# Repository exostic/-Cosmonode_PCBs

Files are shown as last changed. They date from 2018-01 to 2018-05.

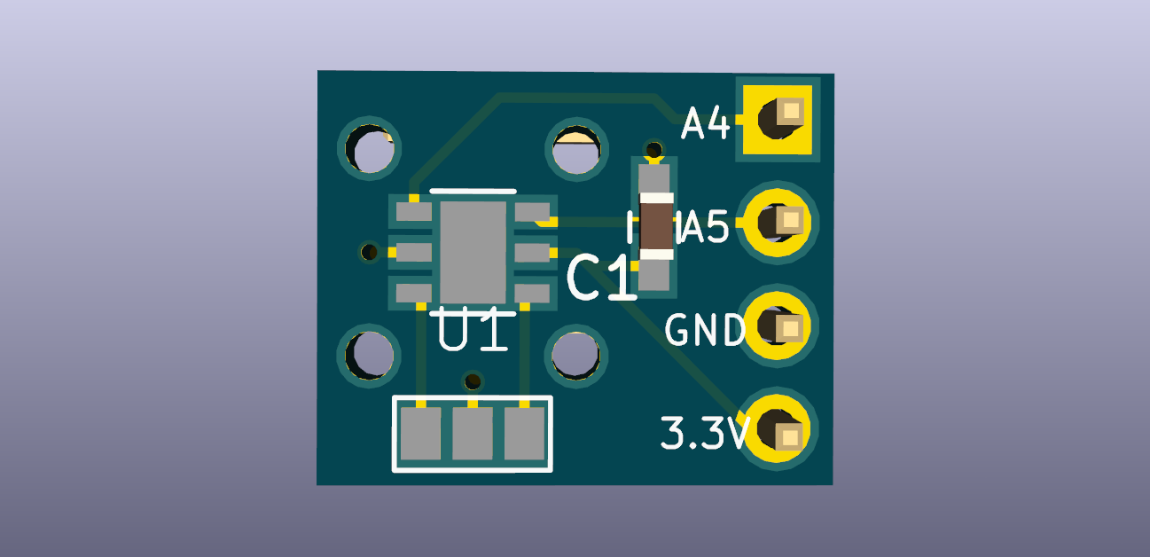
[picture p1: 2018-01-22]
Cosmonode_ext01/docs/Cosmonode_ext01.png

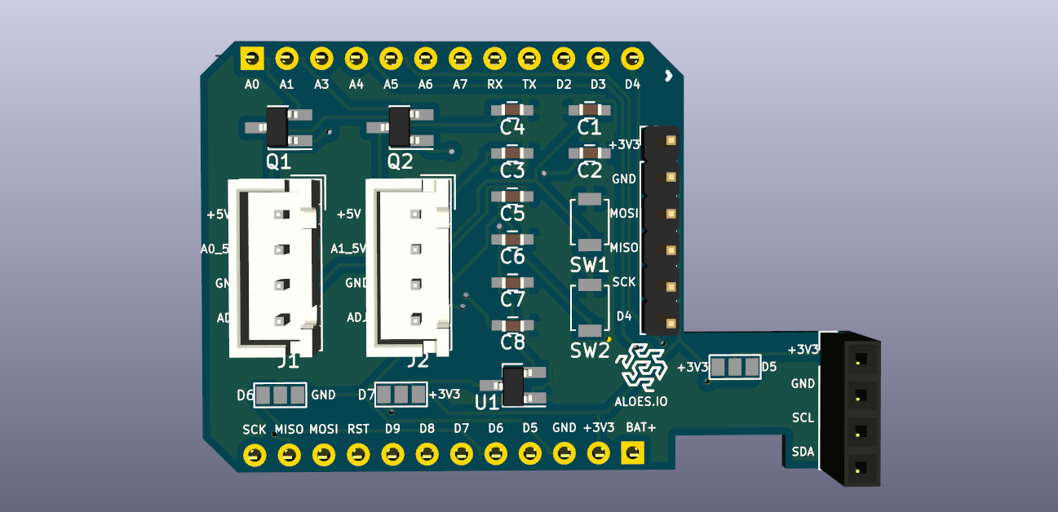
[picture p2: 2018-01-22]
Cosmonode_ext02/docs/Cosmonode_ext02.png

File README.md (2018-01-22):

# Cosmonode v0.7

Universal node, plug and play extensions to ease sensors connection.

## Features

	- Compile and flash with Arduino IDE
	- MCU = ATMega328P-AU
	- radio = RN2483 / RFM69CW ( communications based on LoRaWan or MySensors protocol )
	- 3.3V regulation ( XC6206P332MR )
	- Powered by 3.7V LiPo battery ( 2 pins JST connector )
	- Battery charging ( MCP7831 )
	- State LED's
	- Jumpers to activate radio reset, LED's, on/off switch
	- Button for reset / config mode, or anything else!
	- ATSHA204 to allow hardware unique signature ( no use with RN2483 )

## Projects

Each directory contains Kicad plans, 3D plans, gerber, descriptive .png and .pdf files.

	- ext01 : BME280, Temperature + Humidity + Pression sensor ( only here for the footprint )
	- ext02 : XKC-Y25, Liquid level sensor
	- ext03 : Various connectors ( I2C, Digital, Analog )
	- ext04 : PT100 3 wire, Temperature sensor
	- ext05 : ISP header + micro USB to TTL 
	- ext06 : Analog pH Sensor - BNC probe (WIP)
	- ext07 : MHZ19, CO2 sensor

## Board pinout

	A0 = /
	A1 = /
	A2 = ATSHA204 Input
	A3 = Battery voltage report
	A4 = SDA
	A5 = SCL
	A6 = * LED, jumper J9 ( used as RN2483 Tx )
	A7 = * LED, jumper J14 ( used as RN2483 Rx )
	D0 = RX
	D1 = TX
	D2 = * WakeInterrupt from RN2483, jumper J6 - RFM69 DI0
	D3 = ButtonInterrupt, jumper JP2 ( used to chose mode )
	D4 = /
	D5 = /
	D6 = /
	D7 = /
	D8 = /
	D9 = * RN2483 Reset, jumper J3 - RFM69 Reset
	D10 = RN2483 Rx - RFM69 NSS
	D11 = RN2483 Tx - RFM69 MOSI
	D12 = RFM69 MISO
	D13 = RFM69 SCK
	*optionnal, solder jumper

## Roadmap

--> changelog.md

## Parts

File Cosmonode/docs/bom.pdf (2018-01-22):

Cosmonode

Reference Value | Footprint
U1 | ATMEGA328P-AU | Housings_QFP:TQFP-32_7x7mm_Pitch0.8mm
C2 | 100nF | Capacitors_SMD:C_0603_HandSoldering
C1 | 100nF | Capacitors_SMD:C_0603_HandSoldering
C7 | 100nF | Capacitors_SMD:C_0603_HandSoldering
C3 | 100nF | Capacitors_SMD:C_0603_HandSoldering
R3 | 10k | Resistors_SMD:R_0603_HandSoldering
R8 | 1M | Resistors_SMD:R_0603_HandSoldering
R9 | 470k | Resistors_SMD:R_0603_HandSoldering
C5 | 47uF | Capacitors_Tantalum_SMD:CP_Tantalum_Case-A_EIA-3216-18_Reflow
C6 | 4.7uF | Capacitors_SMD:C_0603_HandSoldering
C8 | 100nF | Capacitors_SMD:C_0603_HandSoldering
R7 | 100k | Resistors_SMD:R_0603_HandSoldering
U5 | XC6206P332MR | TO_SOT_Packages_SMD:TSOT-23
U6 | ATSHA204 | TO_SOT_Packages_SMD:TSOT-23
R4 | 1k | Resistors_SMD:R_0603_HandSoldering
R5 | 1k | Resistors_SMD:R_0603_HandSoldering
C4 | 47uF | Capacitors_Tantalum_SMD:CP_Tantalum_Case-A_EIA-3216-18_Reflow
R6 | | 0 Resistors_SMD:R_0603_HandSoldering
SW1 | SW_DIP_x01 | Buttons_Switches_THT:SW_Tactile_SPST_Angled_PTS645Vx58-2LFS
Y1 | Crystal_GND2 | SMD-RESONATOR-8MHZ-33PF:X3-SMD-3.6X1.3X0.8MM
J1 | CONN_01X12 | Pin_Headers:Pin_Header_Straight_1x12_Pitch2.54mm
J2 | CONN_01X12 | Pin_Headers:Pin_Header_Straight_1x12_Pitch2.54mm
J4 | OSHW | Symbols:OSHW-Logo_7.5x8mm_Copper
U2 | RFM69CW | w_rf_modules:RFM12B_SMD
J5 | CONN_01X02 | Connectors_JST:JST_PH_B2B-PH-K_02x2.00mm_Straight
J10 | WEEE_Logo | Symbols:WEEE-Logo_4.2x6mm_SilkScreen
J11 | Aloes_Logo | Aloes:Aloes
J12 | Aloes_mini_Logo | Aloes:Aloes_mini
U3 | RN2483 | RN2483:RN2483
U7 | MCP73811T-420I/OT TO_SOT_Packages_SMD:SOT-23-5_HandSoldering
J3 | GS2 | Connectors:GS2
D1 | MBR0520 | Diodes_SMD:D_SOD-123
D3 | LED | LEDs:LED_0603_HandSoldering
R12 | 1k | Resistors_SMD:R_0603_HandSoldering
D2 | MBR0520 | Diodes_SMD:D_SOD-123
R11 | R | Resistors_SMD:R_0603_HandSoldering
J13 | CONN_01X05 | Pin_Headers:Pin_Header_Straight_1x05_Pitch2.54mm
C9 | 100nF | Capacitors_SMD:C_0603_HandSoldering
J8 | USB_OTG | Connectors_USB:USB_Micro-B_Molex-105017-0001
R14 | 1k | Resistors_SMD:R_0603_HandSoldering
R13 | 1k | Resistors_SMD:R_0603_HandSoldering
D4 | LED | LEDs:LED_0603_HandSoldering
D5 | LED | LEDs:LED_0603_HandSoldering
J9 | GS2 | Connectors:GS2
J14 | GS2 | Connectors:GS2
P1 | COAX | sma:EDGE_SMA_5
J6 | GS2 | Connectors:GS2
JP1 | Jumper_NO_Small | Pin_Headers:Pin_Header_Straight_1x02_Pitch2.54mm
JP2 | Jumper_NC_Dual | Pin_Headers:Pin_Header_Straight_1x03_Pitch2.54mm

Datasheet | Description
Good | SMD PMIC%3B LDO%3B Vin 6V%3B 3.0V%3B 200mA%3B Without En%3B 1-Ch
Unavailable | Crypto Authentication%2C Sot-23-3

DOCUMENTATION

MF | Package | Price | MP | Farnell
Torex | SOT-23-3 Torex | 0.58 USD XC6206P302MR
Microchip SOT-23-3 Microchip None | ATSHA204-TSU-T

1608592

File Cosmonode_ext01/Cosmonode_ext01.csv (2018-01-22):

Reference | Value | Footprint | Datasheet | Price | Package | MF | Availability | Description
J1 | CONN_01X04 | Pin_Headers:Pin_Header_Angled_1x04_Pitch2.54mm
U1 | SI7020-A20-YM0R | SI7020-A20-YM0R:SON100P300X300X80-7N | SI7020-A20-YM0R | 3.20 USD | DFN-6 Silicon Labs | Silicon Labs | Unavailable | Digital Temperature/Humidity Sensor 6-Pin DFN T/R
J3 | GS3 | Connectors:GS3
C1 | 100nF | Capacitors_SMD:C_0603_HandSoldering
J2 | CONN_01X01 | Wire_Pads:SolderWirePad_single_1-2mmDrill
J4 | CONN_01X01 | Wire_Pads:SolderWirePad_single_1-2mmDrill
J5 | CONN_01X01 | Wire_Pads:SolderWirePad_single_1-2mmDrill
J6 | CONN_01X01 | Wire_Pads:SolderWirePad_single_1-2mmDrill

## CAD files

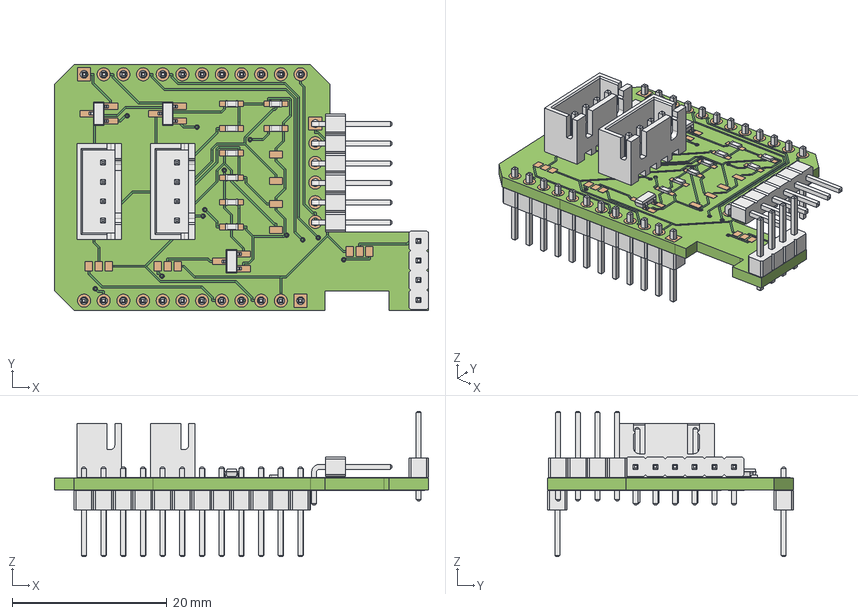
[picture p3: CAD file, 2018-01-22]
Cosmonode_ext02/3d/Cosmonode_ext02.fcstd
48.3 x 31.8 x 18.7 mm
Board
J9
J4
C1
C2
C3
C4
C5
C6
C7
C8
Q1
Q2
U1
J1
J2
J3
J10
F_Cu_0
bPad_107
tPad_108
B_Cu_31

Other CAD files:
Cosmonode_ext02/3d/Cosmonode_ext02.stl

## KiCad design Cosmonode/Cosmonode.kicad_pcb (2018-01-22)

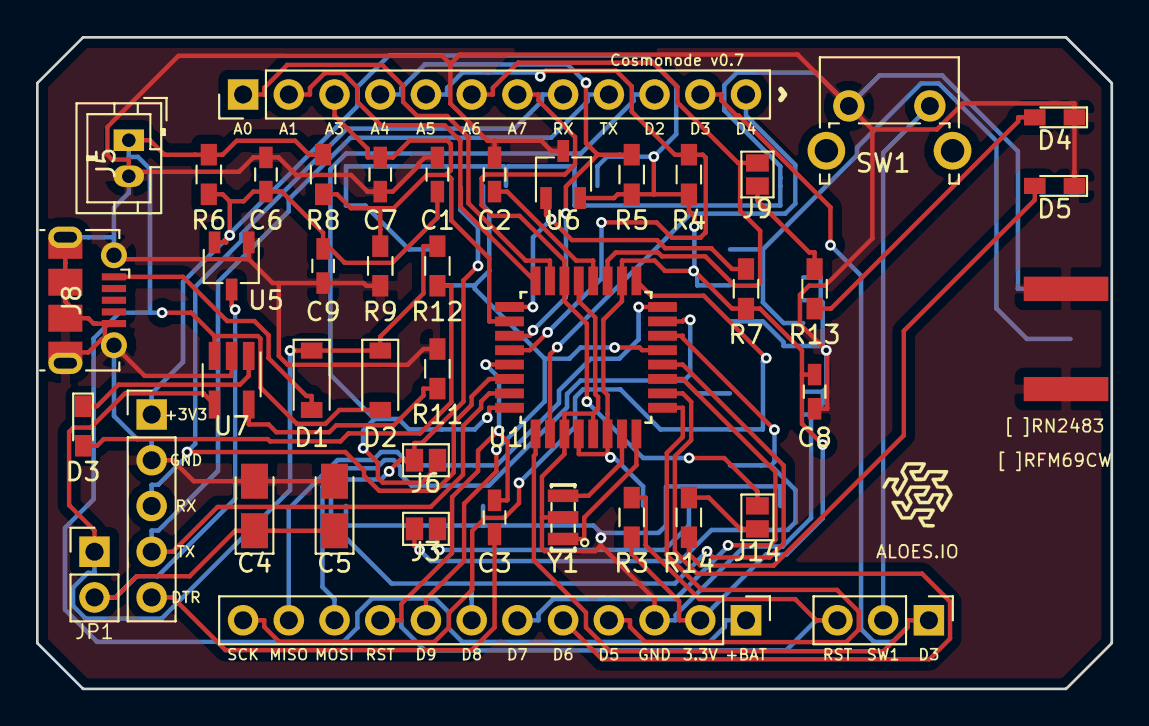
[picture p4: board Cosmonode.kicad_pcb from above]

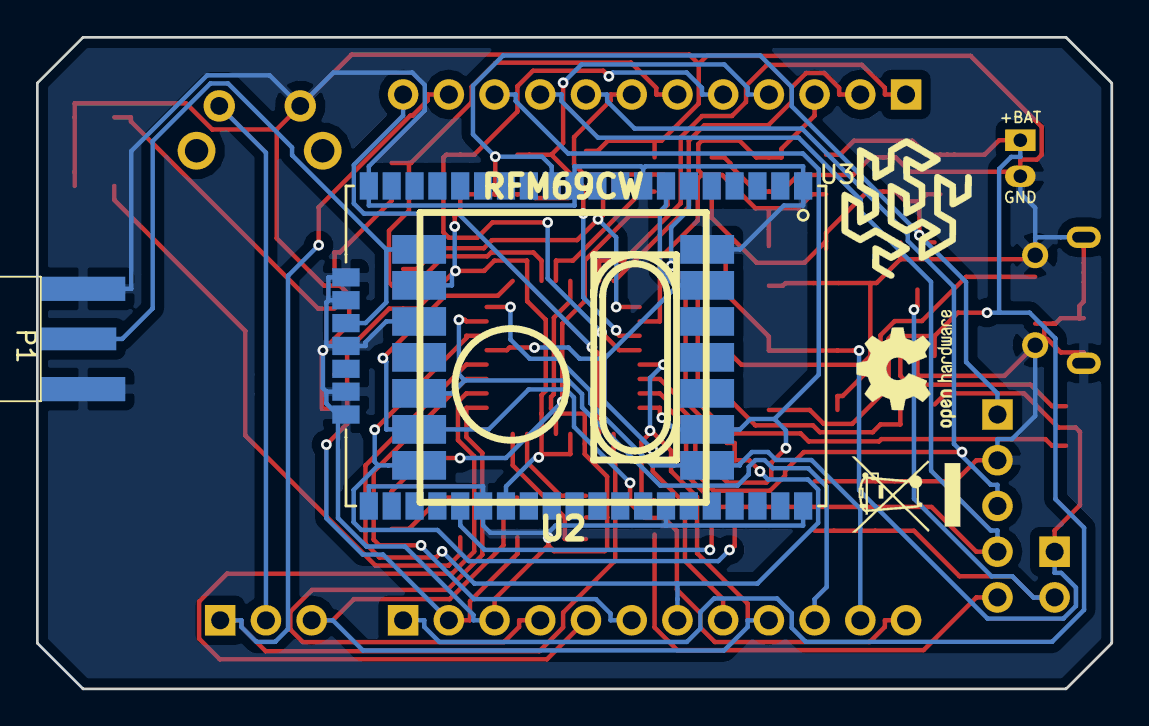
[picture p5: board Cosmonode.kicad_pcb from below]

Board: 2 copper layers, 59.7 x 36.2 mm, 49 parts (6 on the bottom side), 43 nets.

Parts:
C1, C2, C3, C7, C8, C9: 100nF; C_0603_HandSoldering
C4, C5: 47uF; CP_Tantalum_Case-A_EIA-3216-18_Reflow
C6: 4.7uF; C_0603_HandSoldering
D1, D2: MBR0520; D_SOD-123
D3, D4, D5: LED; LED_0603_HandSoldering
J1, J2: CONN_01X12; Pin_Header_Straight_1x12_Pitch2.54mm
J3, J6, J9, J14: GS2
J4: OSHW; OSHW-Logo2_7.3x6mm_SilkScreen
J5: CONN_01X02; JST_PH_B2B-PH-K_02x2.00mm_Straight
J8: USB_OTG; USB_Micro-B_Molex-105017-0001
J10: WEEE_Logo; WEEE-Logo_4.2x6mm_SilkScreen
J11: Aloes_Logo; Aloes
J12: Aloes_mini_Logo; Aloes_mini
J13: CONN_01X05; Pin_Header_Straight_1x05_Pitch2.54mm
JP1: Jumper_NO_Small; Pin_Header_Straight_1x02_Pitch2.54mm
JP2: Jumper_NC_Dual; Pin_Header_Straight_1x03_Pitch2.54mm
P1: COAX; EDGE_SMA_5
R3: 10k; R_0603_HandSoldering
R4, R5, R12, R13, R14: 1k; R_0603_HandSoldering
R6: 0; R_0603_HandSoldering
R7: 100k; R_0603_HandSoldering
R8: 1M; R_0603_HandSoldering
R9: 470k; R_0603_HandSoldering
R11: R; R_0603_HandSoldering
SW1: SW_DIP_x01; SW_Tactile_SPST_Angled_PTS645Vx58-2LFS
U1: ATMEGA328P-AU; TQFP-32_7x7mm_Pitch0.8mm
U2: RFM69CW; RFM12B_SMD
U3: RN2483
U5: XC6206P332MR; TSOT-23
U6: ATSHA204; TSOT-23
U7: MCP73811T-420I/OT; SOT-23-5_HandSoldering
Y1: Crystal_GND2; X3-SMD-3.6X1.3X0.8MM

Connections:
+3V3: C1.1, C6.1, C8.2, C9.1, J2.2, J13.1, R3.1, R4.1, R5.1, R6.1, R7.2, U1.4, U1.6, U1.18, U2.9, U3.12, U3.34, U5.2, U6.2
+BATT: D2.2, J2.1, J5.1, R6.2, R8.1, U7.3
/AREF: C2.2, U1.20
/RN2483_RST: J3.1, U3.32
A0: J1.1, U1.23
A1: J1.2, U1.24
A2: R7.1, U1.25, U6.1
A3: C7.2, J1.3, R8.2, R9.1, U1.26
A4: J1.4, R5.2, U1.27
A5: J1.5, R4.2, U1.28
A6: J1.6, J9.2, U1.19
A7: J1.7, J14.2, U1.22
ANT: P1.1, U2.8, U3.23
D2: J1.10, J6.1, U1.32, U2.2
D3: J1.11, JP2.1, U1.1
D4: J1.12, U1.2
D5: J2.4, U1.9
D6: J2.5, U1.10
D7: J2.6, U1.11
D8: J2.7, J6.2, U1.12, U3.6
D9: J2.8, U1.13, U2.6, U3.7
D10: J3.2, U1.14, U2.14
D11/MOSI: J2.10, U1.15, U2.12
D12/MISO: J2.11, U1.16, U2.1
D13/SCK: J2.12, U1.17, U2.13
DTR: C3.2, J13.5
GND: C1.2, C2.1, C4.2, C5.2, C6.2, C7.1, C8.1, C9.2, D4.1, D5.1, J2.3, J5.2, J8.5, J8.6, J13.2, P1.2, P1.3, P1.4, P1.5, R9.2, R11.1, SW1.1, U1.3, U1.5, U1.21, U2.7, U2.10, U3.1, U3.8, U3.11, U3.20, U3.21, U3.22, U3.24, U3.26, U3.27, U3.28, U3.33, U3.41, U3.47, U5.1, U6.3, U7.2, Y1.2
unnamed: C4.1, C5.1, JP1.2, U5.3
unnamed: D1.1, D2.1, JP1.1, R12.2, U7.4
unnamed: D3.1, U7.1
unnamed: D3.2, R12.1
unnamed: D4.2, R13.1
unnamed: D5.2, R14.1
unnamed: J9.1, R13.2
unnamed: J14.1, R14.2
unnamed: JP2.2, SW1.2
unnamed: R11.2, U7.5
unnamed: U1.7, Y1.3
unnamed: U1.8, Y1.1
RST: C3.1, J2.9, JP2.3, R3.2, U1.29
RX: J1.8, J13.3, U1.30
TX: J1.9, J13.4, U1.31
VDD: D1.2, J8.1

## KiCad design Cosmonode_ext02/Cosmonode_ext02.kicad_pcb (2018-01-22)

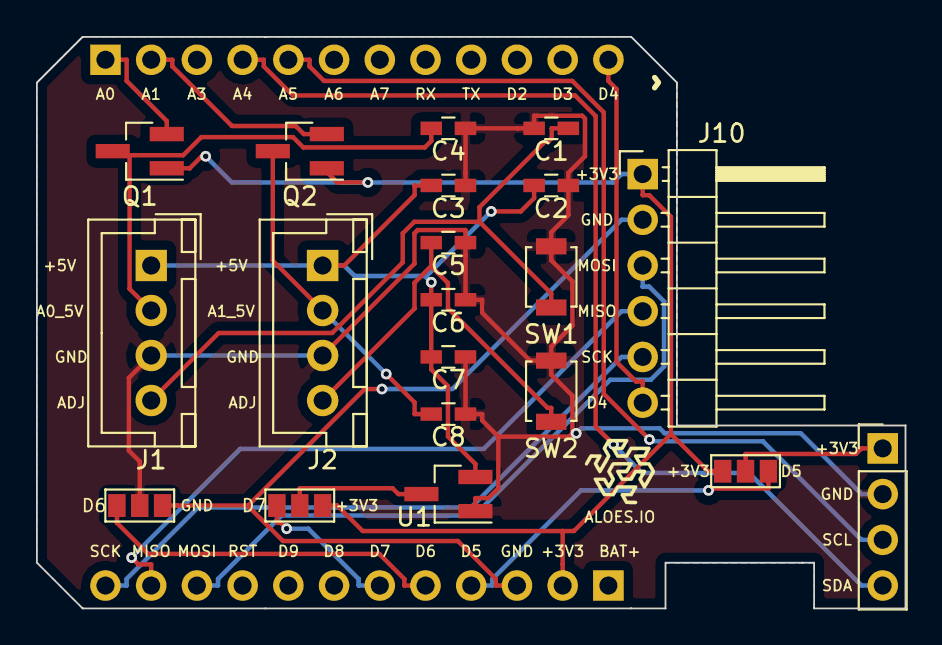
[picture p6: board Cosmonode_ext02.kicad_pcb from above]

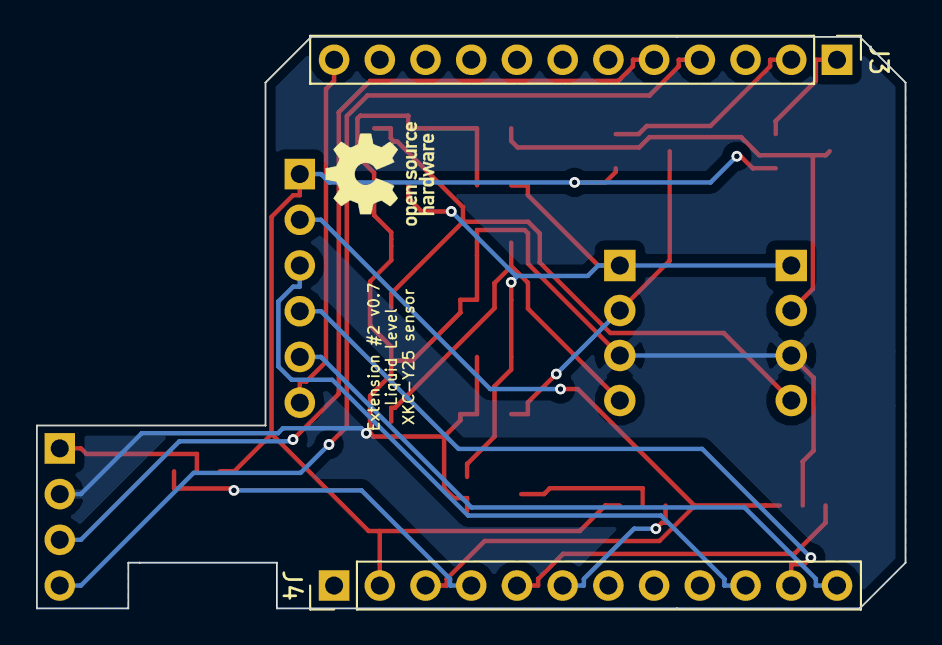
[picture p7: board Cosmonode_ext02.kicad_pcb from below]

Board: 2 copper layers, 48.3 x 31.8 mm, 24 parts (3 on the bottom side), 21 nets.

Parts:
C1, C3, C4, C5, C7, C8: 100nF; C_0603_HandSoldering
C2, C6: 10uF; C_0603_HandSoldering
J1, J2: CONN_01X04; JST_XH_B04B-XH-A_04x2.50mm_Straight
J3, J4: CONN_01X12; Socket_Strip_Straight_1x12_Pitch2.54mm
J5, J6, J12: GS3
J7: Aloes_Logo; Aloes_mini
J8: OSHW_Logo; OSHW-Logo_5.7x6mm_SilkScreen
J9: CONN_01X04; Socket_Strip_Straight_1x04_Pitch2.54mm
J10: CONN_01X06; Pin_Header_Angled_1x06_Pitch2.54mm
Q1, Q2: BSS138; SOT-23_Handsoldering
SW1, SW2: SW_Push; SW_SPST_B3U-1000P
U1: XC6206P502MR; SOT-23_Handsoldering

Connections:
+3V3: J4.2, J5.3, J10.1, J12.3, Q1.1, Q2.1
+5V: C2.1, C3.1, C6.1, C7.1, J1.1, J2.1, U1.2
A0: J3.1, Q1.2
A0_5V: C4.1, J1.2, Q1.3
A1: J3.2, Q2.2
A1_5V: C8.1, J2.2, Q2.3
A4: J3.4, J9.4
A5: J3.5, J9.3
D4: J3.12, J10.6
D5: J4.4, J12.1
D6: J4.5, J6.1
D7: J4.6, J5.1
GND: J4.3, J6.3, J10.2
MISO: J4.11, J10.4
MOSI: J4.10, J10.3
unnamed: C1.1, C2.2, C3.2, C4.2, C5.1, C6.2, C7.2, C8.2, J1.3, J2.3, J6.2, J9.2, SW1.2, SW2.2, U1.1
unnamed: C1.2, J1.4, SW1.1
unnamed: C5.2, J2.4, SW2.1
unnamed: J5.2, U1.3
unnamed: J9.1, J12.2
SCK: J4.12, J10.5

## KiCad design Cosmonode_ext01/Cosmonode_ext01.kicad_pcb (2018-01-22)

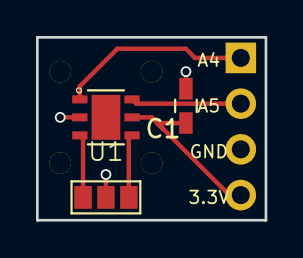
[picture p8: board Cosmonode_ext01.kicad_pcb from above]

Board: 2 copper layers, 12.7 x 10.2 mm, 8 parts (1 on the bottom side), 6 nets.

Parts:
C1: 100nF; C_0603_HandSoldering
J1: CONN_01X04; Pin_Header_Angled_1x04_Pitch2.54mm
J2, J4, J5, J6: CONN_01X01; SolderWirePad_single_1-2mmDrill
J3: GS3
U1: SI7020-A20-YM0R; SON100P300X300X80-7N

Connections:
+3V3: C1.1, J1.4, U1.5
A4: J1.1, U1.1
A5: J1.2, U1.6
GND: C1.2, J1.3, J3.2, U1.2
unnamed: J3.1, U1.4
unnamed: J3.3, U1.3

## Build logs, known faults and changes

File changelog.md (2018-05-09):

# Roadmap

### v0.9 ( Future )

- 4 layers PCB ( x - VCC - GND - y ) ( price x 5 )

### v0.8 ( WIP )

- optionnal GND D6 - battery report
- change battery monitoring circuit - Vi -- 470K -- A3 (Vo) -- 470K -- D6 (GND)
- add IPX connector
- Switch to ATMega32U4 ?  STM32L072CZ ?
- move 2 pins JST for easier access when extension mounted
- use another MFRC522 breakout board ( smaller )
- reduce global node size 
- add on/off switch on PCB - correct circuit ( jumper JP1 unuseful in v 0.7 )
- power manager - SPI connector on extension ( D6 - GND, D5 - 3.3V )
- revert ext01 pins header on ext02 ( SDA - SCL - GND - 3.3V )
- fix I2C problem ( related to voltage ? 4.2 V LDO trouble ? USB input ?)
- correct D4 & D5 circuit ( add 3.3V input ? )

### v0.7 

- Removed mounting hole MK1
- change format ( length : 46 --> 52 mm )
- change LED positions ( visible from outside )
- Custom button ( angled 90°, access from the left )
- Add jumper to choose SW1 button's function ( RST or D3 )
- Add native I2C header to all extensions ( change format ) --> extension01 ( BME280 - 4pins )
- Add native SoftwareSerial to all extensions ( D4/D5 ) --> RC522 NFC reader
- Removed MP2540 ( flash memory )
- Custom extension01 --> include SF2 filter with Si7021 

### v0.6

- Placed RN2483 + RFM69CW footprints on the Bottom layer
- Added VDD jumper ( you may add a on/off switch )
- Removed BSS123 for radio reset regulation

### v0.5

- Changed form factor ( mostly pins header, previous version deprecated )
- Moved radio to the bottom layer
- Tested RN2483 integration
- Port SMA ( antenna )
- Add Blocking diodes
- Battery charging ( MCP7381 )
